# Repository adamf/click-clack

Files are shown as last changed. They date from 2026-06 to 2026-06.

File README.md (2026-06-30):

# click-clack

A Chronos-style chess clock built on ESP32-S3 with dual SPI OLEDs and Cherry MX switches.

## Layout

```
click-clack/
├── firmware/        PlatformIO project (ESP32-S3 + Arduino + U8g2)
│   ├── platformio.ini
│   └── src/
│       └── main.cpp
├── hardware/
│   ├── schematic.txt    ASCII wiring diagram for perfboard build
│   └── pinout.md        Pin assignments
└── case/
    ├── click-clack.scad  Parametric OpenSCAD case
    ├── render-preview.png Assembled render
    ├── fitcheck.png      Interior component fit check
    └── stl/              Ready-to-slice meshes (STL + Bambu 3MF)
```

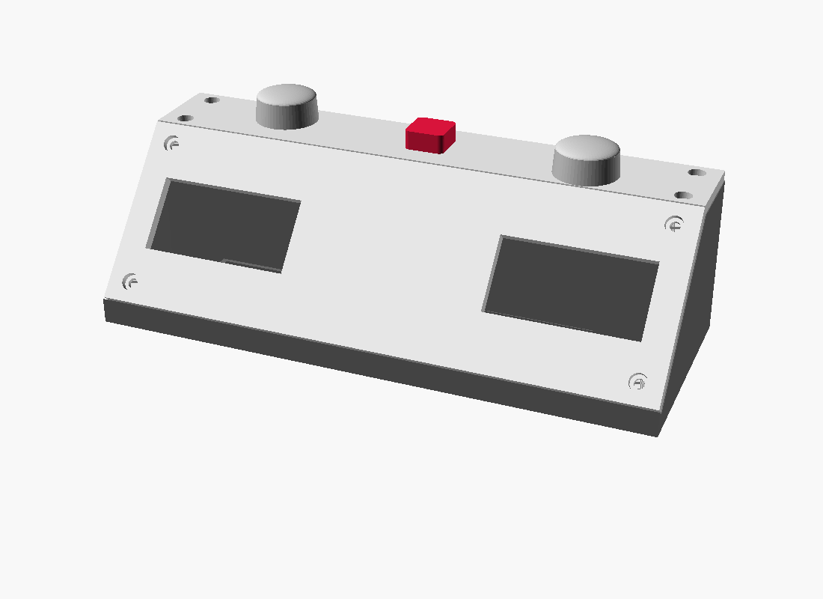
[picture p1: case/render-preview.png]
assembled case


## Hardware

- MCU: ESP32-S3-WROOM-1 DevKitC
- Displays: 2× 2.42" SSD1309 128×64 SPI OLED
- Switches: 3× Cherry MX (2 clock buttons + 1 center button, Chronos-style)
- Power: 1S LiPo + USB-C TP4056 + MT3608 boost
- Buzzer: passive piezo

See `hardware/pinout.md` for the full pin map and `hardware/schematic.txt` for wiring.

## Build

```
cd firmware
pio run -t upload
pio device monitor
```

## Case / 3D printing (Bambu Lab)

The case copies the classic **Chronos** shape — a steep, tilted **screen
face** and a flat **top** for the buttons — close to the real thing
(~210 × 80 × 63 mm; the depth is opened up a touch past the original 70 mm for
easier assembly). It's three printed parts: a lower **shell** that carries
the Chronos silhouette, a flat **display panel** that the OLEDs mount behind,
and a flat **top panel** that the switches mount into. Ready-to-slice meshes
are in `case/stl/` (STL + Bambu Studio's native 3MF); the source of truth is
the parametric `case/click-clack.scad`.

| Part | File | Size | Print orientation |
|---|---|---|---|
| Shell | `click-clack-shell.{stl,3mf}` | 210 × 80 × 59 mm | floor on the bed |
| Display panel | `click-clack-display.{stl,3mf}` | 209 × 70 × 4 mm  | flat, screen face on the bed |
| Top panel | `click-clack-top.{stl,3mf}` | 209 × 32 × 4 mm  | flat, top face on the bed |

All three parts fit a 256 × 256 mm Bambu bed (X1 / X1C / P1S / P1P / A1) and
print flat / floor-down with **no supports** — the two faces are separate flat
panels, so nothing is ever printed as an overhang. (The **A1 mini** at
180 × 180 is too small for the 210 mm width.)

Slice in **Bambu Studio** (drop in the 3MF, or import the STL):

- **Filament:** PETG or PLA+ — a chess clock gets slapped, and PETG shrugs off
  the repeated impact better than plain PLA.
- **Layer:** 0.20 mm · **Walls:** 4 perimeters · **Infill:** 20–30 % gyroid.
- **Supports:** none. The USB-C cutout is a short 10 mm bridge, the switch
  reliefs open upward, and every boss/pillar is vertical.
- **Adhesion:** 5 mm brim on the shell — 210 mm of flat footprint can lift at
  the corners without one.

### How to print it

Start to finish on a Bambu Lab printer:

1. **Install Bambu Studio** (free, from the Bambu Lab site) and pick your
   printer + nozzle (0.4 mm) the first time you open it.
2. **Load the parts.** `File → Import` the three meshes in `case/stl/` (or just
   `click-clack-plate.3mf`, which lays all three out for you). They arrive in
   the correct orientation — shell floor-down, both panels flat — so **don't
   rotate them**.
3. **Pick the filament** in the top-right dropdown (Bambu PETG HF or any
   PETG/PLA+ you have loaded), and set the print profile to **0.20 mm
   Standard**.
4. **Apply the settings** above: in *Quality* set Wall loops = 4; in *Strength*
   set infill to 20–30 % Gyroid; in *Support* leave supports **off**; in
   *Others → Brim* choose Outer brim, 5 mm. (Save these as a custom process
   preset and you only do it once.)
5. **Slice** and sanity-check the preview: roughly ~6–8 h and ~150 g of
   filament for all three parts. Scrub the layer slider — you should see no
   support structures.
6. **Print.** Send over the network or drop the `.3mf`/`.gcode` on the SD card.
   Use a clean PEI plate; for PETG, a light glue-stick layer stops it bonding
   *too* hard. First-layer adhesion across the 210 mm shell is the main risk —
   that's what the brim is for.
7. **After printing:** peel the brim off, then press M3 heat-set inserts into
   the shell bosses with a soldering iron (~200 °C, square and let cool). The
   two panels screw down into them last, once the electronics are mounted.

No Bambu printer? The same STLs slice fine in PrusaSlicer/Cura, or upload them
to a print service (see `BOM.md`).

### Built to take a beating

Players hammer these buttons, so the top panel is engineered for it:

- 4 mm panels seated in a recess around their whole perimeter — no corner-only
  span.
- M3 screw bosses at every panel corner clamp the panels down.
- The button panel is a short ~33 mm-deep strip carried on all four edges
  (ridge rib at the front, back wall at the back, side walls left/right), so a
  thumb on a button barely flexes it — no floor pillars needed, which also
  keeps the floor clear for the boards.
- A transverse **ridge rib** (with a wiring notch) backs the seam where the two
  faces meet.
- Each MX cutout has a proper 1.5 mm clip land with an underside relief, so the
  switches actually snap in and stay put under load.

Use M3 brass heat-set inserts in the shell bosses and M3 screws (8–10 mm)
through the counterbores in the panels.

### How everything mounts

Every component has a locating feature in the model — nothing relies on glue
alone. Generic modules vary between sellers, so the relevant sizes are
**parameters at the top of `click-clack.scad`** (`OLED_PCB_*`, `OLED_HOLE_*`,
`DEVKIT_*`, `TP_*`, `BATT_*`); measure your parts and tweak before printing.

- **Screens (2.42″ OLED modules):** each window on the display panel has four
  **stand-off posts** behind it on the module's mounting-hole pattern, plus
  corner nibs that locate the board outline. The module drops over the posts
  (glass toward the window) and is held with four **M2 self-tapping screws**.
  Set `OLED_HOLE_DX/DY` and `OLED_PCB_W/H` to your module; `OLED_ACT_OFF`
  shifts the posts if your module's active area isn't centred on the board.
- **Switches:** Cherry-MX **plate mount** — the 14 mm cutout has a 1.5 mm clip
  land with an underside relief, so each switch's nylon clips snap in and hold
  it, exactly like a keyboard plate. No extra hardware.
- **USB-C charging:** the **TP4056 board *is* the socket.** It sits flat on a
  small holder against the back wall (side guides + a front stop on 2 mm
  stand-offs) so its USB-C jack lines up with the back-wall cutout. The cutout
  is offset left so it clears the centre-button support pillar.
- **Main board (ESP32-S3-DevKitC-1):** drops into a **cradle** on the floor —
  a guide frame plus four corner stand-offs that lift the pins off the floor.
  The DevKitC has no mounting holes, so the cradle captures it by outline; a
  dab of tape or a printed cap keeps it seated.
- **Battery (1S LiPo):** sits in a walled **bay** on the floor; secure it with
  a strap or double-sided foam tape. Wiring passes front-to-back through the
  notch in the ridge rib.

Rough interior plan: slim battery front-left (tucked under the left screen),
DevKitC on the floor just behind the screen overhang, TP4056 at the back wall,
OLED boards hanging off the display panel. Dry-fit before final assembly — at
80 mm deep it's snug, and a fat 2000 mAh cell won't clear the screens.

Render the fit check yourself with `part="fitcheck"`:

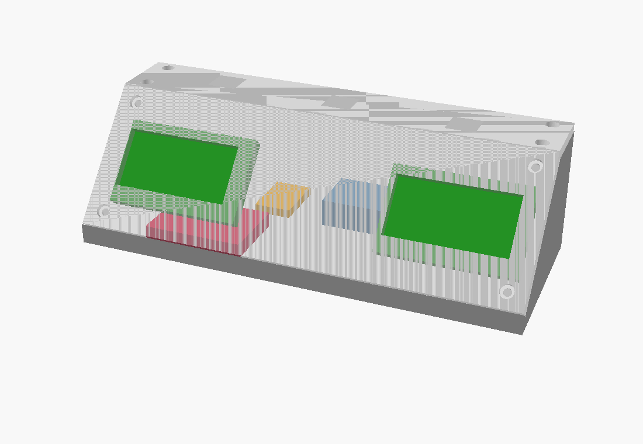
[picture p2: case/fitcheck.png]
interior fit check


Regenerate the meshes after editing the `.scad`:

```
cd case
for p in shell display top; do
  openscad -o stl/click-clack-$p.stl -D "part=\"$p\"" click-clack.scad
done
```

## Controls (Chronos-style, three buttons)

Just two clock buttons and one center button — exactly like a Chronos. The
center button handles everything else through press-and-hold combos.

**Playing:**
- **Your clock button** (left / right): press to end your move and start the opponent
- **Center, tap**: pause / resume
- **Center, tap at flag**: start a fresh game with the loaded time control

**Settings — hold the center button:**
- **Hold center ~1s** (while stopped): enter SETUP (a beep confirms)
- In SETUP: **tap center** = next field · **left** = decrease · **right** = increase
- **Hold center ~1s** again: save, exit, and reset the clocks to the new control

SETUP walks through a **Preset** (common controls applied to both sides), then
per-side base/increment, then the options below.

## Time controls

- Sudden death (e.g. 5+0, 3+0, 1+0)
- Fischer increment (e.g. 3+2, 5+3, 15+10)
- Each side configurable independently (asymmetric / odds games)

## Options (persisted to NVS)

- `stop_on_flag` — freeze game when a flag falls (default ON)
- `beep_on_flag` — buzzer on flag (default ON)
- `beep_on_move` — short click on each move press (default OFF)
- `low_time_warn` — beep at 10s/5s remaining (default ON)
- `brightness` — OLED contrast 0–255
- `default_tc` — time control loaded on power-up

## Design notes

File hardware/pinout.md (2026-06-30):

# Pinout — ESP32-S3-WROOM-1 DevKitC

## SPI bus (shared between both OLEDs)

| Signal | GPIO | Notes |
|---|---|---|
| SCK | 12 | shared |
| MOSI  | 11 | shared |
| DC | 9  | shared (data/command) |
| RST | 8  | shared (tied together, reset both at boot) |
| CS1 | 10 | OLED #1 (Player 1, left) |
| CS2 | 13 | OLED #2 (Player 2, right) |

OLED MISO is unused (write-only). Use HSPI on the ESP32-S3 (`SPI` default
in Arduino-ESP32 maps to FSPI; either is fine — the code uses U8g2's
hardware SPI constructor).

## Buttons (all `INPUT_PULLUP`, switch to GND)

Three buttons, Chronos-style. The center button handles pause/resume and —
held down together with the clock buttons — every setting.

| Button | GPIO |
|---|---|
| Left clock button  | 4  |
| Right clock button | 5  |
| Center | 17 |

GPIO 6, 7, 15, 16 (the old Mode/Set/Up/Down) are now free.

## Output / sense

| Signal | GPIO | Notes |
|---|---|---|
| Buzzer (passive piezo, drive via MOSFET or directly) | 18 | PWM via LEDC |
| Battery sense | 1 | ADC1_CH0, 100k/100k divider from VBAT |
| TP4056 CHRG status | 2 | active LOW when charging |

## Power tree

```
USB-C ──┬── TP4056 (+DW01 protection) ──┬── 1S LiPo (3.0–4.2V) ──┐
        │                               │                       │
        └── (charge only)               └── BAT+ ────────────────┴── MT3608 boost ── 5V ──┬── ESP32-S3 5V pin (LDO → 3.3V)
                                                                                          └── OLED VCC
```

The DevKitC has its own AMS1117 LDO; feed it 5V on the 5V pin (not VIN).
OLEDs run on 3.3V or 5V depending on the breakout — most SSD1309 modules
have an onboard regulator and accept 3.3–5V.

## Reserved / avoid

- GPIO 0, 3, 45, 46 — strapping pins, leave alone
- GPIO 19, 20 — native USB D-/D+
- GPIO 26–32 — used by SPI flash on WROOM-1
- GPIO 33–37 — used by octal PSRAM on WROOM-1 (avoid even on non-PSRAM variants)

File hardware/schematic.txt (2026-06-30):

click-clack — perfboard schematic (ASCII)
==========================================

                              ┌──────────────────────┐
        USB-C  ──────────────►│  TP4056 USB-C w/     │
                              │  DW01 protection     │
                              │                      │
                              │  BAT+  ──┬────────── │──► to MT3608 IN+
                              │  BAT-  ──┼────────── │──► GND
                              │  CHRG  ──┼────────── │──► GPIO2 (status LED tap)
                              └──────────┼───────────┘
                                         │
                                  1S LiPo 2000mAh
                                         │
                                         ▼
                              ┌──────────────────────┐
                              │  MT3608 boost        │
                              │  Vin 3.0–4.2V        │
                              │  Vout set to 5.0V    │
                              └──────────┬───────────┘
                                         │ 5V rail
                ┌────────────────────────┼────────────────────────┐
                │                        │                        │
                ▼                        ▼                        ▼
       ESP32-S3 DevKitC 5V      OLED #1 VCC               OLED #2 VCC
                │                        │                        │
                ▼ (onboard LDO)          ▼                        ▼
              3.3V                      GND                      GND

SPI bus
-------
   ESP32-S3        OLED #1 (Player 1)         OLED #2 (Player 2)
   GPIO12 SCK ───┬── SCK                  ┬── SCK
   GPIO11 MOSI ──┤── MOSI (D1/SDA)        ┤── MOSI (D1/SDA)
                 │                        │
   GPIO10 CS  ───┘── CS                   │
   GPIO13 CS  ──────────────────────────  ┘── CS
   GPIO9  DC  ───┬── DC                   ┬── DC
   GPIO8  RST ───┴── RST                  ┴── RST

Buttons (all to GND, MCU uses internal pull-ups)
------------------------------------------------
   GPIO4  ──[ MX P1 ]── GND      (left clock button)
   GPIO5  ──[ MX P2 ]── GND      (right clock button)
   GPIO17 ──[ MX CENTER ]── GND  (center button — pause + settings combos)

   Just three buttons, Chronos-style. GPIO6/7/15/16 are now free.

Buzzer
------
   GPIO18 ──[ 220Ω ]──┬── piezo + ── GND
                      │
                   (or gate of 2N7000 with piezo to 5V for louder)

Battery sense
-------------
   BAT+ ──[ 100kΩ ]──┬──[ 100kΩ ]── GND
                     │
                     └── GPIO1 (ADC1_CH0)
   max input ≈ 2.1V  (4.2V / 2)

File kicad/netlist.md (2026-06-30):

# click-clack — netlist (source of truth)

This is the human-readable connection list for the perfboard build.
The `.kicad_sch` file mirrors this; if they ever disagree, **this file
wins** and the schematic should be updated to match.

## Reference designators

| Ref | Part |
|---|---|
| U1 | ESP32-S3-WROOM-1 DevKitC-1 |
| U2 | TP4056 USB-C charger module (with DW01 protection) |
| U3 | MT3608 boost converter module (set Vout = 5.0V) |
| DS1 | OLED #1, 2.42" SSD1309 128×64 SPI (Player 1, left) |
| DS2 | OLED #2, 2.42" SSD1309 128×64 SPI (Player 2, right) |
| BT1 | 1S LiPo, 2000–3000 mAh, with built-in protection |
| SW1 | Cherry MX — left clock button |
| SW2 | Cherry MX — right clock button |
| SW3 | Cherry MX — center button (pause + settings combos) |
| BZ1 | Passive piezo buzzer |
| R1 | 100 kΩ — battery sense divider, top |
| R2 | 100 kΩ — battery sense divider, bottom |
| R3 | 220 Ω — buzzer series |

## Power tree

| Net | Connections |
|---|---|
| `USB_5V` | USB-C VBUS → U2.IN+ |
| `USB_GND` | USB-C GND → U2.IN- → GND |
| `BAT+` | U2.BAT+ → BT1.+ → U3.IN+ → R1 (top of divider) |
| `GND` | U2.BAT- → BT1.- → U3.IN- → all module GNDs |
| `+5V` | U3.OUT+ → U1.5V → DS1.VCC → DS2.VCC |
| `+3V3` | U1.3V3 (output from DevKitC LDO; not used externally) |

> The DevKitC has its own LDO. Feed it on the **5V** pin, not VIN.
> Most SSD1309 OLED breakouts accept 3.3–5V; using +5V is safest.

## ESP32-S3 — SPI (shared between both OLEDs)

| Net | ESP32-S3 GPIO | DS1 pin | DS2 pin |
|---|---|---|---|
| `SCK`  | GPIO12 | SCK / D0 | SCK / D0 |
| `MOSI` | GPIO11 | MOSI / D1 | MOSI / D1 |
| `OLED_DC`  | GPIO9  | DC | DC |
| `OLED_RST` | GPIO8  | RST | RST |
| `OLED_CS1` | GPIO10 | CS  | — |
| `OLED_CS2` | GPIO13 | — | CS |

## ESP32-S3 — buttons

All buttons connect MCU pin → MX switch → GND. Use internal `INPUT_PULLUP`,
no external pull-up resistors needed.

| Net | GPIO | Switch |
|---|---|---|
| `BTN_P1` | GPIO4  | SW1 |
| `BTN_P2` | GPIO5  | SW2 |
| `BTN_CENTER` | GPIO17 | SW3 |

GPIO 6, 7, 15, 16 are unused now (free for future expansion).

## ESP32-S3 — output / sense

| Net | GPIO | Connects to |
|---|---|---|
| `BUZZER` | GPIO18 | R3 (220Ω) → BZ1.+ ; BZ1.- → GND |
| `VBAT_SENSE` | GPIO1 (ADC1_CH0) | midpoint of R1/R2 divider |
| `CHRG_STAT` | GPIO2 | U2.CHRG (open-drain, active low) |

### Battery sense divider

```
BAT+ ──[ R1 100k ]──┬──[ R2 100k ]── GND
                    │
                    └──► VBAT_SENSE (GPIO1)
```

Max input ≈ 2.1 V at 4.2 V battery, well within ADC range.

## Decoupling / housekeeping

- 10 µF ceramic across DS1 VCC↔GND and DS2 VCC↔GND, close to each module.
- 100 nF ceramic across U1 5V↔GND.
- The TP4056 and MT3608 modules already include their own input/output caps.

## Notes for the PCB pass (later)

- DS1/DS2 RST is shared. If you ever see only one panel come up, split
  RST onto two GPIOs (e.g. GPIO14 and a free pin) and update firmware.
- The center button does pause/resume (tap) and, held ~1s, opens SETUP;
  inside SETUP the two clock buttons edit values. No special hardware —
  same MX switch as the clock buttons, just a smaller (often red) keycap.
- Avoid GPIO 0/3/45/46 (strapping), 19/20 (USB), 26–37 (flash/PSRAM).

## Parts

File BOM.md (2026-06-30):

# click-clack — Shopping List

There's no single store that carries everything (MCU dev boards, OLEDs,
keyboard switches, LiPo, and 3D-print hardware all live in different
ecosystems). The lists below are grouped by vendor so each cart is
self-contained. Total estimate: **~$70–95** for one clock.

---

## 1. Amazon (fastest, slightly more expensive)

If you want everything in 2 days and don't care about a few dollars:

| Qty | Item | Search term | ~$ |
|---|---|---|---|
| 1 | ESP32-S3-DevKitC-1 (N8R2 or N16R8) | "ESP32-S3-DevKitC-1" | $15 |
| 2 | 2.42" OLED 128×64 SSD1309 SPI, white or yellow | "2.42 inch OLED SSD1309 SPI" | $24 |
| 1 | TP4056 USB-C charging module **with protection** (5-pack) | "TP4056 USB C protection" | $7 |
| 1 | MT3608 boost converter (5-pack) | "MT3608 DC-DC boost" | $6 |
| 1 | 1S LiPo 2000 mAh with JST-PH and protection | "2000mAh 3.7V lipo JST" | $10 |
| 1 | Passive piezo buzzer (assortment) | "passive piezo buzzer 3V" | $6 |
| 1 | M3 heat-set inserts + screws kit | "M3 heat set inserts kit" | $12 |
| 1 | 22 AWG silicone wire assortment | "22 AWG silicone wire kit" | $10 |
| 1 | Perfboard assortment (double-sided, 5×7 / 7×9 cm) | "double sided perfboard" | $8 |

**Amazon subtotal: ~$98** (you'll have leftovers of almost everything)

---

## 2. Mechanical keyboard parts (Amazon, Drop, KBDfans, or NovelKeys)

| Qty | Item | Notes |
|---|---|---|
| 3 (or a 10-pack) | Cherry MX switches | Pick your feel: **MX Brown** = tactile/quiet (recommended for a chess clock at a tournament), **MX Blue** = clicky/loud, **MX Red** = linear |
| 2 | Large round keycaps for the clock buttons | To mimic the big round Chronos buttons. Big-knob / arcade-style 1u caps or jumbo round caps both work; a contrasting colour each side is classic. |
| 1 | Red keycap for the center button | The Chronos's red center button. A red DSA/XDA 1u cap is fine. |

**Estimate: ~$15–25** depending on brand. NovelKeys and KBDfans sell singles; Amazon sells 10-packs of generic-brand "MX-style" switches (Gateron, Outemu) for ~$10 which work fine for this.

---

## 3. DigiKey / Mouser BOM (CSV — see `BOM.csv`)

For just the discrete components (resistors, capacitors), use the included
`BOM.csv` to upload to **DigiKey** (https://www.digikey.com/en/mylists/list/upload)
or **Mouser** (https://www.mouser.com/Bom/UploadBom). Both accept the
columns `Manufacturer Part Number`, `Quantity`, and `Customer Reference`.

The CSV covers resistors, capacitors, and the buzzer driver MOSFET (optional).
**Subtotal: ~$5** plus shipping (which is why I recommend buying these as
part of a bigger order, or getting an assortment from Amazon instead).

---

## 4. 3D print

Ready-to-slice meshes live in `case/stl/` (STL + Bambu Studio 3MF). Either:
- Print at home in **PETG** (recommended — it takes the button-slapping better
  than PLA) or PLA+, ~150g of filament total — **~$3** in material. On a Bambu
  Lab printer just drop in the 3MF; see the README for the full profile.
- Or upload the STLs to **JLCPCB 3D Printing**, **PCBWay**, **Craftcloud**, or
  **Shapeways** — **~$25–40** in MJF or SLA

**Fasteners for assembly** (a cheap M2/M3 assortment covers all of it):
- 8 × **M2 self-tapping screws** (~6 mm) — mount the two OLED modules.
- 8 × **M3 screws** (8–10 mm) + 8 × **M3 brass heat-set inserts** — the two
  panels into the shell bosses.
- A strip of **double-sided foam tape** or a small velcro strap for the battery.

---

## 5. Optional / nice-to-have

| Item | Why |
|---|---|
| Logic analyzer (Saleae clone, ~$10) | Debug SPI if OLEDs don't come up |
| JST-PH crimping kit | Clean battery connection |
| Hot glue + Kapton tape | Strain relief on the LiPo wires |
| Slide switch (SPDT, panel mount) | Hard power switch on the back |

---

## TL;DR cheapest path

**Just buy the Amazon list above plus a 10-pack of Gateron Brown switches
and some blank DSA caps from Amazon.** Total ~$120, you'll have spare
parts for a v2, and everything ships in 2 days. The DigiKey route is
better if you're already placing an order there for other projects.

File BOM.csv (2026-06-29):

Customer Reference | Manufacturer Part Number | Manufacturer | Description | Quantity
R1 | RC0805FR-07100KL | Yageo | RES SMD 100K OHM 1% 1/8W 0805 | 1
R2 | RC0805FR-07100KL | Yageo | RES SMD 100K OHM 1% 1/8W 0805 | 1
R3 | RC0805FR-07220RL | Yageo | RES SMD 220 OHM 1% 1/8W 0805 | 1
C1 | CL21A106KOQNNNE | Samsung | CAP CER 10UF 25V X5R 0805 | 2
C2 | CL21B104KBCNNNC | Samsung | CAP CER 0.1UF 50V X7R 0805 | 3
SW1-7 | MX1A-11NW | Cherry | SWITCH MX BROWN PCB MOUNT | 7
BZ1 | PS1240P02BT | TDK | BUZZER PIEZO 30V 12.2MM TH | 1
Q1 | 2N7000 | onsemi | MOSFET N-CH 60V 200MA TO-92 (optional buzzer driver) | 1

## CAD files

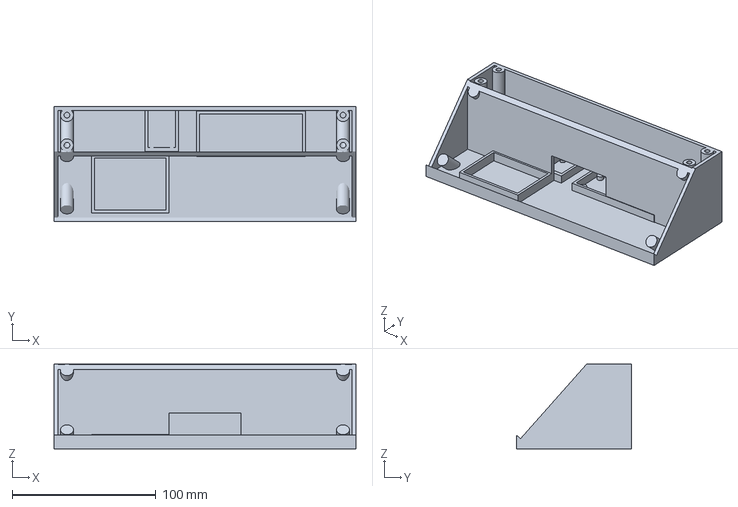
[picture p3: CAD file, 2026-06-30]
case/stl/click-clack-shell.3mf
210.0 x 80.0 x 59.0 mm

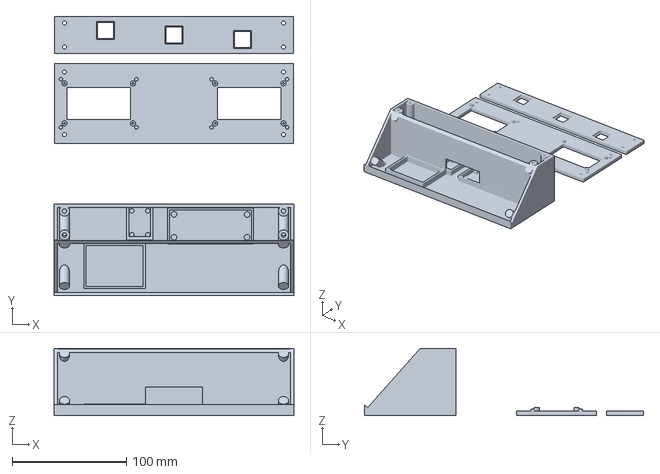
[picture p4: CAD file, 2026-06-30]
case/stl/click-clack-plate.3mf
210.0 x 244.5 x 59.0 mm

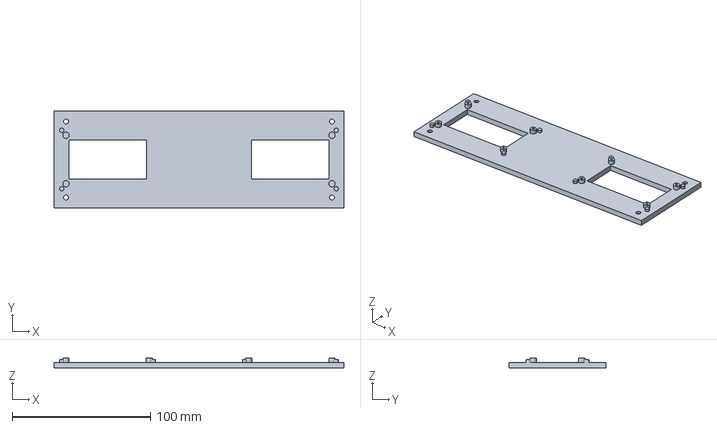
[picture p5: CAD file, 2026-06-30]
case/stl/click-clack-display.3mf
209.4 x 70.2 x 7.00 mm

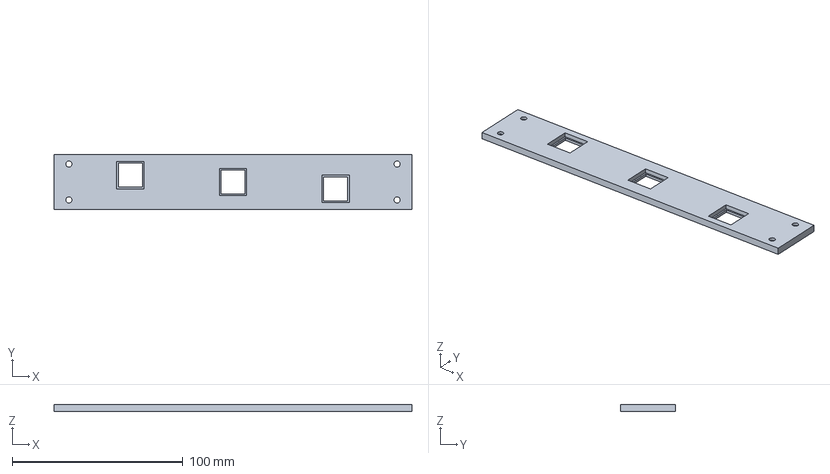
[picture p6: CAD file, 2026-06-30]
case/stl/click-clack-top.3mf
209.4 x 32.4 x 4.00 mm

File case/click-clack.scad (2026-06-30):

// click-clack — Chronos-style chess clock case
// Parametric OpenSCAD.
//
// Shape follows a real Chronos: a steeply TILTED FRONT FACE holding the two
// screens, and a FLAT TOP behind it holding the buttons. Three printed parts,
// all printable flat / floor-down with no supports:
//
//   part = "shell"   -> lower body: floor, front lip, side walls (the Chronos
//                       silhouette), back wall, ridge rib, screw bosses and the
//                       component mounts. Print floor-down.
//   part = "display" -> the tilted screen panel, laid FLAT for printing.
//   part = "top"     -> the flat top button panel, laid FLAT for printing.
//   part = "preview" -> all three assembled (do not print).
//   part = "demo"    -> assembled with representative keycaps (visual only).
//   part = "fitcheck"-> assembly ghosted with component footprints inside.
//   part = "plate"   -> all three parts arranged flat on one build plate.
//
// Print on a Bambu Lab printer (256^3 bed; this is 210 x 80 mm). PETG or PLA+,
// 0.20 mm, 4 walls, 20-30% gyroid, 5 mm brim on the shell, no supports.
// M3 heat-set inserts in the shell bosses; M3 screws through the panels.

part = "preview";

$fn = 48;

// ---------- overall dimensions ----------
// Close to the classic Chronos (~8.25" x 2.75" x 2.5"); the depth is opened up
// a little past the original 70 mm to give the boards and battery room inside.
W        = 210;   // width
D        = 80;    // depth (front-to-back) — compact; the DevKitC tucks behind
                  //   the screen overhang (see the fit-check, part="fitcheck")
FRONT_LIP = 10;   // height of the little vertical lip at the very front
H_TOP    = 63;    // height of the flat top (and the back wall)
Y_RIDGE  = 7;     // depth position of the ridge where the two faces meet

WALL     = 2.8;
FLOOR_T  = 3.0;
PANEL_T  = 4.0;   // thickness of the display / top panels
LEDGE    = 2.0;   // (unused spacing reserved)
CLEAR    = 0.3;   // panel fit clearance

// ---------- display panel geometry (the tilted face: B -> C) ----------
B = [-D/2, FRONT_LIP];   // front-lip top
C = [Y_RIDGE, H_TOP];    // ridge
disp_dY  = C[0] - B[0];                 // run (depth)
disp_dZ  = C[1] - B[1];                 // rise (height)
disp_tilt = atan(disp_dZ / disp_dY);    // from horizontal
disp_len  = sqrt(disp_dY*disp_dY + disp_dZ*disp_dZ);
disp_midY = (B[0] + C[0]) / 2;
disp_midZ = (B[1] + C[1]) / 2;

// ---------- flat top geometry (C -> E) ----------
top_depth = D/2 - Y_RIDGE;     // depth of the flat top strip
top_midY  = (Y_RIDGE + D/2) / 2;

// ---------- OLED windows (on the display panel) ----------
OLED_W = 56;
OLED_H = 28;
OLED_GAP_FROM_CENTER = 38;   // centerline to inner edge of each window
OLED_SLOPE_OFFSET = 0;       // shift up/down the slope (panel-local y')

// ---------- MX switch cutouts (on the flat top panel) ----------
MX         = 14.0;
MX_PLATE_T = 1.5;
MX_RELIEF  = 16.0;

// Button positions on the flat top, panel-local [x, y] (y measured from the
// flat-top centre; +y toward the back). Slight Chronos diagonal.
BTN_L = [-60,  4];    // left clock button  (toward back)
BTN_R = [ 60, -4];    // right clock button (toward front)
BTN_C = [  0,  0];    // center button (the red one)
BUTTONS = [BTN_L, BTN_R, BTN_C];

// ---------- USB-C cutout (low on the back wall) ----------
// Aligned to a TP4056 board lying flat on 2 mm stand-offs (socket ~6 mm up).
// Off-centre so the board clears the centre button / its wiring.
USBC_W = 11;
USBC_H = 6;
USBC_Z = 3.5;
USBC_X = -30;

// ============================================================
// internal component mounts
// ------------------------------------------------------------
// NB: generic modules vary between sellers. These are typical values for the
// common Waveshare / lcdwiki-style parts — MEASURE YOUR OWN and tweak. Every
// mount locates its part; nothing here is glued-in-place only.
// ============================================================
// 2.42" SSD1309 OLED module (one per screen)
OLED_PCB_W    = 65;    // module board width
OLED_PCB_H    = 41;    // module board height
OLED_ACT_OFF  = 0;     // active-area offset from board centre, up the slope (y')
OLED_HOLE_DX  = 60;    // mounting-hole spacing across the board
OLED_HOLE_DY  = 35;    // mounting-hole spacing up/down the board
OLED_STAND_H  = 3.0;   // stand-off height (board sits this far off the panel)
OLED_PILOT_R  = 0.8;   // M2 self-tapping pilot hole

// ESP32-S3-DevKitC-1 — on the floor just behind the screen overhang
DEVKIT_L = 70; DEVKIT_W = 26; DEVKIT_CL = 0.8; DEVKIT_STAND = 3;
DEVKIT_POS = [32, 21];

// TP4056 USB-C charger board (USB-C on a short edge) — at the back wall cutout
TP_L = 27; TP_W = 18; TP_CL = 0.6; TP_STAND = 2;

// 1S LiPo — front-left floor, tucked UNDER the left screen, so a slim cell is
// what fits the height. Default ≈ a 753448 (~1500 mAh, 7.5 x 34 x 48 mm).
BATT_L = 48; BATT_W = 34; BATT_H = 7; BATT_CL = 1.0;
BATT_POS = [-52, -14];

// ---------- screws / bosses ----------
BOSS_R   = 4.5;
INSERT_R = 2.0;
SCREW_CLEAR_R = 1.8;
CBORE_R  = 3.2;
CBORE_D  = 2.4;

// display-panel screw positions, panel-local [x, y'] (y' along the slope)
DISP_SCREWS = [[-(W/2-9), -(disp_len/2-8)], [ (W/2-9), -(disp_len/2-8)],
               [-(W/2-9),  (disp_len/2-8)], [ (W/2-9),  (disp_len/2-8)]];
// top-panel screw positions, panel-local [x, y]
TOP_SCREWS  = [[-(W/2-9), -(top_depth/2-6)], [ (W/2-9), -(top_depth/2-6)],
               [-(W/2-9),  (top_depth/2-6)], [ (W/2-9),  (top_depth/2-6)]];

// ============================================================
// body silhouette
// ============================================================
profile = [[-D/2, 0], [D/2, 0], [D/2, H_TOP], [Y_RIDGE, H_TOP], [-D/2, FRONT_LIP]];

// solid Chronos body: profile is (depth, height); extrude across the width
module body_solid() {
    translate([-W/2, 0, 0])
        multmatrix([[0,0,1,0],[1,0,0,0],[0,1,0,0],[0,0,0,1]])
            linear_extrude(W) polygon(profile);
}

// place children on the tilted display face: x' across width, y' up the slope,
// z' = 0 on the outer face, +z' outward.
module on_display() {
    translate([0, disp_midY, disp_midZ])
        rotate([disp_tilt, 0, 0])
            children();
}

// place children on the flat top: x across width, y depth-from-top-centre,
// z = 0 on the outer (top) surface, +z up.
module on_top() {
    translate([0, top_midY, H_TOP])
        children();
}

// ============================================================
// panels — flat for printing (z = 0 cosmetic/bed face)
// ============================================================
module oled_window(sx) {
    cx = sx * (OLED_GAP_FROM_CENTER + OLED_W/2);
    translate([cx - OLED_W/2, OLED_SLOPE_OFFSET - OLED_H/2, -1])
        cube([OLED_W, OLED_H, PANEL_T + 2]);
}

module mx_cut(pos) {
    translate([pos[0], pos[1], 0]) {
        translate([-MX/2, -MX/2, -1]) cube([MX, MX, PANEL_T + 2]);
        translate([-MX_RELIEF/2, -MX_RELIEF/2, MX_PLATE_T])
            cube([MX_RELIEF, MX_RELIEF, PANEL_T]);
    }
}

module screw_hole(pos) {
    translate([pos[0], pos[1], -1]) cylinder(h = PANEL_T + 2, r = SCREW_CLEAR_R);
    translate([pos[0], pos[1], -0.01]) cylinder(h = CBORE_D, r = CBORE_R);
}

// OLED retention on the back of the display panel: 4 stand-off posts at the
// module's hole pattern (board drops over them, M2 self-tappers clamp it) plus
// low corner nibs that locate the board outline.
module oled_mount(sx) {
    cx = sx * (OLED_GAP_FROM_CENTER + OLED_W/2);
    cy = OLED_SLOPE_OFFSET - OLED_ACT_OFF;
    translate([cx, cy, PANEL_T]) {
        for (hx = [-1, 1], hy = [-1, 1])
            translate([hx*OLED_HOLE_DX/2, hy*OLED_HOLE_DY/2, 0])
                difference() {
                    cylinder(h = OLED_STAND_H, r = 2.3);
                    translate([0,0,-0.1]) cylinder(h = OLED_STAND_H + 0.2, r = OLED_PILOT_R);
                }
        // locating nibs at the board corners
        for (nx = [-1, 1], ny = [-1, 1])
            translate([nx*(OLED_PCB_W/2 + 0.6), ny*(OLED_PCB_H/2 + 0.6), 0])
                cylinder(h = 2.0, r = 1.6);
    }
}

module display_panel_flat() {
    w = W - 2*CLEAR;
    l = disp_len - 2*CLEAR;
    union() {
        difference() {
            translate([-w/2, -l/2, 0]) cube([w, l, PANEL_T]);
            oled_window(-1); oled_window(1);
            for (s = DISP_SCREWS) screw_hole(s);
        }
        oled_mount(-1); oled_mount(1);
    }
}

module top_panel_flat() {
    w = W - 2*CLEAR;
    l = top_depth - 2*CLEAR;
    difference() {
        translate([-w/2, -l/2, 0]) cube([w, l, PANEL_T]);
        for (b = BUTTONS) mx_cut(b);
        for (s = TOP_SCREWS) screw_hole(s);
    }
}
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

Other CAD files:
case/stl/click-clack-display.stl
case/stl/click-clack-plate.stl
case/stl/click-clack-shell.stl
case/stl/click-clack-top.stl

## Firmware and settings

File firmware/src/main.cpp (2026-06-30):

// click-clack — Chronos-style chess clock
// ESP32-S3 + 2x SSD1309 SPI OLED + 3x Cherry MX
//
// Just three buttons, like a real Chronos:
//   - LEFT / RIGHT  : the two clock buttons (one per player)
//   - CENTER        : the single button between the displays
//
// Play:
//   Tap your own clock button to end your move and start the opponent.
//   Tap CENTER          : pause / resume.
//   Tap CENTER at FLAG  : start a fresh game with the loaded time control.
//
// Settings (no extra buttons — it's all combos on CENTER):
//   Hold CENTER (~1s) while stopped : enter SETUP (a beep confirms).
//   In SETUP:
//     Tap CENTER  : move to the next field
//     Tap LEFT    : decrease the value     (P1 button = "-")
//     Tap RIGHT   : increase the value     (P2 button = "+")
//     Hold CENTER : save, exit, and reset the clocks to the new control
//
// SETUP fields: Preset (applies to both sides), then per-side base/increment,
// then the options (stop-on-flag, beeps, low-time warning, brightness).

#include <Arduino.h>
#include <U8g2lib.h>
#include <SPI.h>
#include <Bounce2.h>
#include <Preferences.h>
#include <esp_timer.h>

// ---------- pins ----------
static constexpr int PIN_SCK   = 12;
static constexpr int PIN_MOSI  = 11;
static constexpr int PIN_DC    = 9;
static constexpr int PIN_RST   = 8;
static constexpr int PIN_CS1   = 10;
static constexpr int PIN_CS2   = 13;

static constexpr int PIN_BTN_P1     = 4;   // left clock button
static constexpr int PIN_BTN_P2     = 5;   // right clock button
static constexpr int PIN_BTN_CENTER = 17;  // single center button

static constexpr int PIN_BUZZER = 18;
static constexpr int PIN_VBAT   = 1;

// ---------- displays ----------
// Two SSD1309 panels sharing SCK/MOSI/DC/RST, separate CS.
U8G2_SSD1309_128X64_NONAME0_F_4W_HW_SPI oled1(
    U8G2_R0, /*cs=*/PIN_CS1, /*dc=*/PIN_DC, /*reset=*/PIN_RST);
U8G2_SSD1309_128X64_NONAME0_F_4W_HW_SPI oled2(
    U8G2_R0, /*cs=*/PIN_CS2, /*dc=*/PIN_DC, /*reset=*/U8X8_PIN_NONE);

// ---------- buttons ----------
struct Btn { Bounce b; int pin; };
Btn p1{{}, PIN_BTN_P1}, p2{{}, PIN_BTN_P2}, bCenter{{}, PIN_BTN_CENTER};
Btn* allBtns[] = {&p1, &p2, &bCenter};

// ---------- state ----------
enum class State : uint8_t { IDLE, RUNNING, PAUSED, FLAG, SETUP };
State state = State::IDLE;

// time control: per-side base (ms) and increment (ms)
struct TC {
    uint32_t base_ms[2];
    uint32_t inc_ms[2];
};
TC tc;                 // currently loaded
int64_t remain_us[2];  // live remaining microseconds
uint8_t  active = 0;   // 0=P1, 1=P2 (the side whose clock is ticking)
bool     flagged[2] = {false, false};
int64_t  last_tick_us = 0;

// options
struct Options {
    bool stop_on_flag   = true;
    bool beep_on_flag   = true;
    bool beep_on_move   = false;
    bool low_time_warn  = true;
    uint8_t brightness  = 200;
} opt;

Preferences prefs;

// ---------- setup mode ----------
// Common symmetric time controls {base minutes, increment seconds}.
static const uint16_t PRESETS[][2] = {
    {1, 0}, {2, 1}, {3, 0}, {3, 2}, {5, 0}, {5, 3},
    {10, 0}, {10, 5}, {15, 10}, {25, 0}, {30, 0}, {60, 0},
};
static const int N_PRESETS = sizeof(PRESETS) / sizeof(PRESETS[0]);
static const int N_FIELDS  = 10;   // see fieldText()

uint8_t setup_field = 0;
int     preset_idx  = 2;   // 3+0 by default

// center-button press tracking
uint32_t center_down_ms = 0;
bool     center_long_fired = false;
static constexpr uint32_t HOLD_MS = 900;

// ---------- helpers ----------
void beep(uint16_t freq, uint16_t ms) {
    ledcWriteTone(0, freq);
    delay(ms);
    ledcWriteTone(0, 0);
}

void loadPrefs() {
    prefs.begin("clack", false);
    tc.base_ms[0] = prefs.getULong("b0", 3UL * 60 * 1000);   // 3+0 default
    tc.base_ms[1] = prefs.getULong("b1", 3UL * 60 * 1000);
    tc.inc_ms[0]  = prefs.getULong("i0", 0);
    tc.inc_ms[1]  = prefs.getULong("i1", 0);
    opt.stop_on_flag  = prefs.getBool("sof", true);
    opt.beep_on_flag  = prefs.getBool("bof", true);
    opt.beep_on_move  = prefs.getBool("bom", false);
    opt.low_time_warn = prefs.getBool("ltw", true);
    opt.brightness    = prefs.getUChar("br", 200);
}

void savePrefs() {
    prefs.putULong("b0", tc.base_ms[0]);
    prefs.putULong("b1", tc.base_ms[1]);
    prefs.putULong("i0", tc.inc_ms[0]);
    prefs.putULong("i1", tc.inc_ms[1]);
    prefs.putBool("sof", opt.stop_on_flag);
    prefs.putBool("bof", opt.beep_on_flag);
    prefs.putBool("bom", opt.beep_on_move);
    prefs.putBool("ltw", opt.low_time_warn);
    prefs.putUChar("br", opt.brightness);
}

void resetClocks() {
    remain_us[0] = (int64_t)tc.base_ms[0] * 1000;
    remain_us[1] = (int64_t)tc.base_ms[1] * 1000;
    flagged[0] = flagged[1] = false;
    state = State::IDLE;
}

// format ms as MM:SS or H:MM:SS or with tenths under 20s
void fmtTime(int64_t us, char* out, size_t n) {
    if (us < 0) us = 0;
    uint32_t total_ms = us / 1000;
    uint32_t s = total_ms / 1000;
    uint32_t h = s / 3600;
    uint32_t m = (s % 3600) / 60;
    uint32_t sec = s % 60;
    if (us < 20LL * 1000 * 1000) {
        uint32_t tenths = (total_ms % 1000) / 100;
        snprintf(out, n, "%lu.%lu", (unsigned long)s, (unsigned long)tenths);
    } else if (h > 0) {
        snprintf(out, n, "%lu:%02lu:%02lu",
                 (unsigned long)h, (unsigned long)m, (unsigned long)sec);
    } else {
        snprintf(out, n, "%lu:%02lu", (unsigned long)m, (unsigned long)sec);
    }
}

// ---------- drawing ----------
void drawClockFace(U8G2& d, int side, bool isActive) {
    d.clearBuffer();
    char buf[16];
    fmtTime(remain_us[side], buf, sizeof(buf));

    // big time, centered
    d.setFont(u8g2_font_logisoso32_tn);
    int w = d.getStrWidth(buf);
    int x = (128 - w) / 2;
    d.drawStr(x, 46, buf);

    // top label
    d.setFont(u8g2_font_6x10_tr);
    const char* label = (side == 0) ? "P1" : "P2";
    d.drawStr(2, 9, label);

    // tc summary right
    char tcbuf[16];
    snprintf(tcbuf, sizeof(tcbuf), "%lu+%lu",
             (unsigned long)(tc.base_ms[side] / 60000),
             (unsigned long)(tc.inc_ms[side] / 1000));
    int tw = d.getStrWidth(tcbuf);
    d.drawStr(128 - tw - 2, 9, tcbuf);

    if (flagged[side]) {
        d.drawStr(45, 62, "FLAG");
    } else if (state == State::PAUSED) {
        d.drawStr(45, 62, "PAUSE");
    } else if (isActive && state == State::RUNNING) {
        d.drawBox(0, 60, 128, 4);
    }
    d.sendBuffer();
}

// one line of text for a SETUP field
void fieldText(int i, char* out, size_t n) {
    switch (i) {
    case 0:
        snprintf(out, n, "Preset: %u+%u",
                 PRESETS[preset_idx][0], PRESETS[preset_idx][1]);
        break;
    case 1: snprintf(out, n, "L base: %lu min", (unsigned long)(tc.base_ms[0] / 60000)); break;
    case 2: snprintf(out, n, "L inc:  %lu sec", (unsigned long)(tc.inc_ms[0]  / 1000));  break;
    case 3: snprintf(out, n, "R base: %lu min", (unsigned long)(tc.base_ms[1] / 60000)); break;
    case 4: snprintf(out, n, "R inc:  %lu sec", (unsigned long)(tc.inc_ms[1]  / 1000));  break;
    case 5: snprintf(out, n, "Stop flag: %s", opt.stop_on_flag  ? "ON" : "OFF"); break;
    case 6: snprintf(out, n, "Beep flag: %s", opt.beep_on_flag  ? "ON" : "OFF"); break;
    case 7: snprintf(out, n, "Beep move: %s", opt.beep_on_move  ? "ON" : "OFF"); break;
    case 8: snprintf(out, n, "Low warn:  %s", opt.low_time_warn ? "ON" : "OFF"); break;
    case 9: snprintf(out, n, "Bright: %u", opt.brightness); break;
    default: out[0] = '\0'; break;
    }
}

void drawSetup(U8G2& d) {
    d.clearBuffer();
    d.setFont(u8g2_font_6x12_tr);
    d.drawStr(2, 10, "SETUP");

    // a window of three fields centred on the cursor
    int start = (setup_field <= 1) ? 0
              : (setup_field >= N_FIELDS - 1) ? N_FIELDS - 3
              : setup_field - 1;
    for (int i = 0; i < 3; i++) {
        int idx = start + i;
        if (idx < 0 || idx >= N_FIELDS) continue;
        char field[24], line[28];
        fieldText(idx, field, sizeof(field));
        snprintf(line, sizeof(line), "%c%s", (idx == setup_field) ? '>' : ' ', field);
        d.drawStr(2, 26 + i * 13, line);
    }

    d.setFont(u8g2_font_4x6_tr);
    d.drawStr(2, 63, "P1:-  P2:+  C:next  holdC:save");
    d.sendBuffer();
}

void render() {
    if (state == State::SETUP) {
        drawSetup(oled1);
        drawSetup(oled2);
    } else {
        drawClockFace(oled1, 0, active == 0);
        drawClockFace(oled2, 1, active == 1);
    }
}

// ---------- ticking ----------
void tickClocks() {
    int64_t now = esp_timer_get_time();
    int64_t dt = now - last_tick_us;
    last_tick_us = now;
    if (state != State::RUNNING) return;
    remain_us[active] -= dt;

    // low-time warnings (10s, 5s) on the active side
    if (opt.low_time_warn) {
        static int last_warn[2] = {-1, -1};
        int64_t s = remain_us[active] / 1000000;
        if ((s == 10 || s == 5) && last_warn[active] != (int)s) {
            last_warn[active] = s;
            beep(2200, 60);
        }
        if (remain_us[active] > 12LL * 1000000) last_warn[active] = -1;
    }

    if (remain_us[active] <= 0) {
        remain_us[active] = 0;
        flagged[active] = true;
        if (opt.beep_on_flag) beep(1500, 250);
        if (opt.stop_on_flag) {
            state = State::FLAG;
        }
        // if not stopping on flag, the clock just sits at 0 and the
        // opponent can keep playing — Chronos "no-stop" behavior
    }
}

// ---------- input handling ----------
void onPlayerPress(int side) {
    if (state == State::IDLE) {
        // first press starts the OPPONENT's clock (you press to end your move)
        active = 1 - side;
        last_tick_us = esp_timer_get_time();
        state = State::RUNNING;
        if (opt.beep_on_move) beep(2000, 20);
        return;
    }
    if (state == State::RUNNING && active == side) {
        // your move ended: add your increment, switch
        remain_us[side] += (int64_t)tc.inc_ms[side] * 1000;
        active = 1 - side;
        if (opt.beep_on_move) beep(2000, 20);
    }
}

void adjBase(int side, int delta) {
    int64_t v = (int64_t)tc.base_ms[side] + delta * 60000;
    if (v < 60000) v = 60000;                          // 1 min min
    if (v > 180LL * 60 * 1000) v = 180LL * 60 * 1000;  // 3 hr max
    tc.base_ms[side] = v;
}
void adjInc(int side, int delta) {
    int64_t v = (int64_t)tc.inc_ms[side] + delta * 1000;
    if (v < 0) v = 0;
    if (v > 60000) v = 60000;
    tc.inc_ms[side] = v;
}

// edit the current SETUP field; delta is -1 (left) or +1 (right)
void editField(int delta) {
    switch (setup_field) {
    case 0:
        preset_idx = (preset_idx + delta + N_PRESETS) % N_PRESETS;
        tc.base_ms[0] = tc.base_ms[1] = (uint32_t)PRESETS[preset_idx][0] * 60000UL;
        tc.inc_ms[0]  = tc.inc_ms[1]  = (uint32_t)PRESETS[preset_idx][1] * 1000UL;
        break;
    case 1: adjBase(0, delta); break;
    case 2: adjInc(0, delta);  break;
    case 3: adjBase(1, delta); break;
    case 4: adjInc(1, delta);  break;
    case 5: opt.stop_on_flag  = !opt.stop_on_flag;  break;
    case 6: opt.beep_on_flag  = !opt.beep_on_flag;  break;
    case 7: opt.beep_on_move  = !opt.beep_on_move;  break;
    case 8: opt.low_time_warn = !opt.low_time_warn; break;
    case 9: {
        int v = (int)opt.brightness + delta * 16;
        if (v < 16) v = 16;
        if (v > 255) v = 255;
        opt.brightness = v;
        oled1.setContrast(opt.brightness);
        oled2.setContrast(opt.brightness);
        break;
    }
    }
}

// CENTER, short tap — meaning depends on the current state
void centerTap() {
    switch (state) {
    case State::SETUP:
        setup_field = (setup_field + 1) % N_FIELDS;
        break;
    case State::RUNNING:
        state = State::PAUSED;
        break;
    case State::PAUSED:
        last_tick_us = esp_timer_get_time();
        state = State::RUNNING;
        break;
    case State::FLAG:
    case State::IDLE:
        resetClocks();   // start a fresh game with the loaded control
        break;
    }
}

// CENTER, held past HOLD_MS
void centerHold() {
    if (state == State::SETUP) {
        savePrefs();
        resetClocks();
        beep(2400, 40); delay(40); beep(1800, 40);   // "saved" chirp
    } else if (state != State::RUNNING) {
        state = State::SETUP;
        setup_field = 0;
        beep(1800, 40); delay(40); beep(2400, 40);    // "entering" chirp
    }
    // while RUNNING a hold does nothing — a tap pauses instead
}

// ---------- setup / loop ----------
void setupButtons() {
    for (Btn* b : allBtns) {
        pinMode(b->pin, INPUT_PULLUP);
        b->b.attach(b->pin);
        b->b.interval(5);
    }
}

void setup() {
    Serial.begin(115200);

    SPI.begin(PIN_SCK, -1, PIN_MOSI, -1);

    oled1.begin();
    oled2.begin();

    setupButtons();

    ledcSetup(0, 2000, 8);
    ledcAttachPin(PIN_BUZZER, 0);

    loadPrefs();
    oled1.setContrast(opt.brightness);
    oled2.setContrast(opt.brightness);
    resetClocks();
    last_tick_us = esp_timer_get_time();

    render();
}

void loop() {
    for (Btn* b : allBtns) b->b.update();

    // clock buttons: edit values in SETUP, otherwise play
    if (p1.b.fell()) { if (state == State::SETUP) editField(-1); else onPlayerPress(0); }
    if (p2.b.fell()) { if (state == State::SETUP) editField(+1); else onPlayerPress(1); }

    // center button: short tap vs long hold
    if (bCenter.b.fell()) {
        center_down_ms = millis();
        center_long_fired = false;
    }
    if (bCenter.b.read() == LOW && !center_long_fired &&
        (millis() - center_down_ms) > HOLD_MS) {
        centerHold();
        center_long_fired = true;
    }
    if (bCenter.b.rose() && !center_long_fired) {
        centerTap();
    }

    tickClocks();

    static uint32_t last_render = 0;
    uint32_t now = millis();
    if (now - last_render >= 50) {  // 20 Hz
        last_render = now;
        render();
    }
}

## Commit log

2026-06-29 Rework case for Bambu Lab printing and button durability
    The case existed only as OpenSCAD source with several geometry bugs, and
    Bambu Studio can't slice .scad. Rebuild it so it's both printable and able
    to survive players slapping the buttons.
    Bottom shell:
    - Replace the dead/broken bottom() module and the non-functional top
    recess with a clean stepped cavity that forms a continuous perimeter
    ledge for the top plate (single watertight manifold, verified).
    - Add six M3 screw posts (corners + front/back centre) and two interior
    support pillars that rise from the floor directly behind the player
    paddles, so a hard press transfers into the shell instead of flexing
    the plate. Thicker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
    [click-clack-bottom.3mf, click-clack-bottom.stl, click-clack-plate.3mf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]
2026-06-29 Add step-by-step printing instructions to README
    Claude-Session: https://claude.ai/code/session_01RmVZgsFGRPRMdjashrFswr
2026-06-30 Switch to Chronos 3-button layout (2 clock + 1 center)
    Match the real Chronos: two clock buttons and a single center button, with
    no separate Mode/Set/Up/Down. Settings are driven by center-button combos.
    Case:
    - Top face rearranged Chronos-style: the two clock buttons sit diagonally
    (left toward the back, right toward the front) for big round keycaps, the
    single center "red" button up top, and the two OLEDs side-by-side and
    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
    [click-clack-bottom.3mf, click-clack-bottom.stl, click-clack-plate.3mf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]
2026-06-30 Add keycap visualisation mode (part="demo")
    Render-only preview that fits representative keycaps to the assembled case —
    big round caps on the two clock buttons and a red cap on the center button —
    to show the Chronos look. Not a printable part; switch cutouts are unchanged.
    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
    [click-clack.scad]
2026-06-30 Rebuild case to the real Chronos shape (tilted screen face + flat top)
    The previous case was a single-slope wedge; a real Chronos is two-faceted —
    a steep TILTED SCREEN FACE and a separate FLAT TOP for the buttons. Rebuild
    around that silhouette and size it to the classic Chronos (~210 x 70 x 63 mm,
    8.25 x 2.75 x 2.5"), which is shallower and more upright than the old model.
    Now three printed parts, all flat / floor-down with no supports (the two
    faces are separate flat panels, so nothing is an overhang):
    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
    [click-clack-bottom.3mf, click-clack-bottom.stl, click-clack-display.3mf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]
2026-06-30 Deepen case to 80 mm for assembly room
    Open the depth from 70 to 80 mm so the DevKitC, battery and the two OLED
    boards have room inside; the 2.42" screens still fit the display face with
    margin (PCB outer edge 98.5 mm vs 102.2 mm inner wall, and the corner screws
    clear the boards). Shape and proportions unchanged. Meshes, render and README
    dimensions regenerated.
    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
    [click-clack-display.3mf, click-clack-display.stl, click-clack-plate.3mf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]
2026-06-30 Add internal mounts: OLED screens, DevKitC, TP4056, battery
    The case had outer features but nothing to actually fasten the components.
    Add a locating mount for each, all parametric (generic modules vary, so the
    sizes live at the top of click-clack.scad):
    - Screens: four M2 self-tap stand-off posts behind each window on the module
    hole pattern, plus corner locating nibs. Module drops over the posts, glass
    to the window.
    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
    [click-clack-display.3mf, click-clack-display.stl, click-clack-plate.3mf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]
2026-06-30 Add fitcheck mode; resolve interior packing; add plate STL
    part="fitcheck" ghosts the assembly and drops the component footprints
    (screens, DevKitC, TP4056, battery) inside so clearances can be eyeballed —
    and it immediately caught a collision: the screens hang into the front
    interior and the tall DevKitC overlapped them.
    Fix without growing the case (kept compact at 210x80x63):
    - Removed the floor button-pillars. They were carried over from the old wide
    flat plate; the new button panel is a short ~33 mm strip carried on all four
    edges, so it doesn't need them — and they were what blocked the boards.
    - DevKitC now sits on the cleared floor just behind the screen overhang;
    battery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
    [click-clack-display.3mf, click-clack-display.stl, click-clack-plate.3mf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]
2026-06-30 Add interior fit-check render to the repo
    case/fitcheck.png shows the ghosted assembly with the screen/DevKitC/TP4056/
    battery footprints inside, so the clearances are visible without opening
    OpenSCAD. Referenced from the README mounting section and the layout tree.
    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
